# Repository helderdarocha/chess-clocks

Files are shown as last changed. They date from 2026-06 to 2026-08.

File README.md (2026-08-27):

# Chess Clocks (Arduino)

First model (Clock 1) using 3xAA batteries, TM1637 displays, and led-powered arcade buttons 
in a resin-coated wooden case.
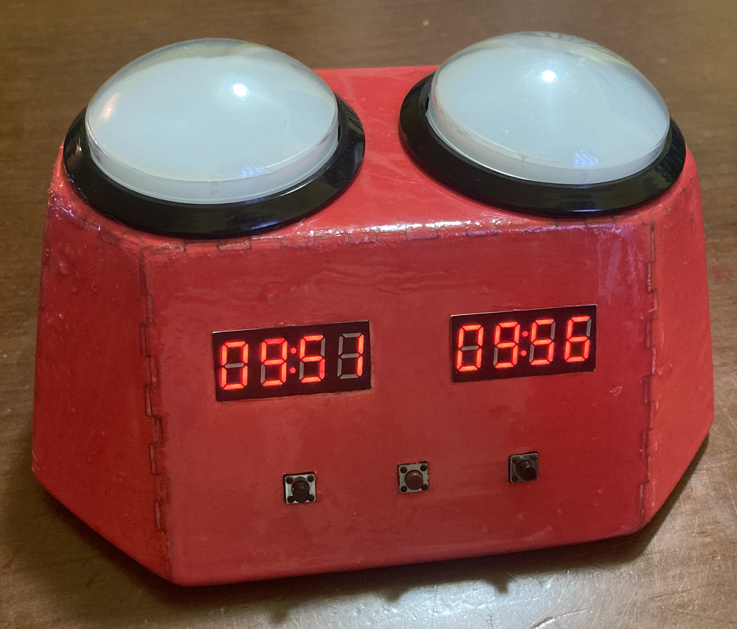
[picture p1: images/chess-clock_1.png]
Chess Clock 1


Old model (Clock 2) using 3xAA batteries, HT16K33 displays and pull-up resistors.
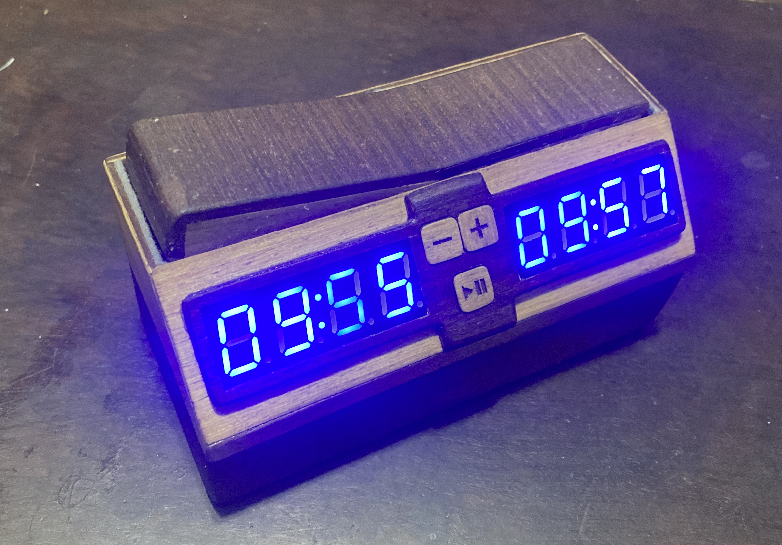
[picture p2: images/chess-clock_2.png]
Chess Clock 2


Current model (Clock 3) using Li-ion battery with TP4056 charger module.
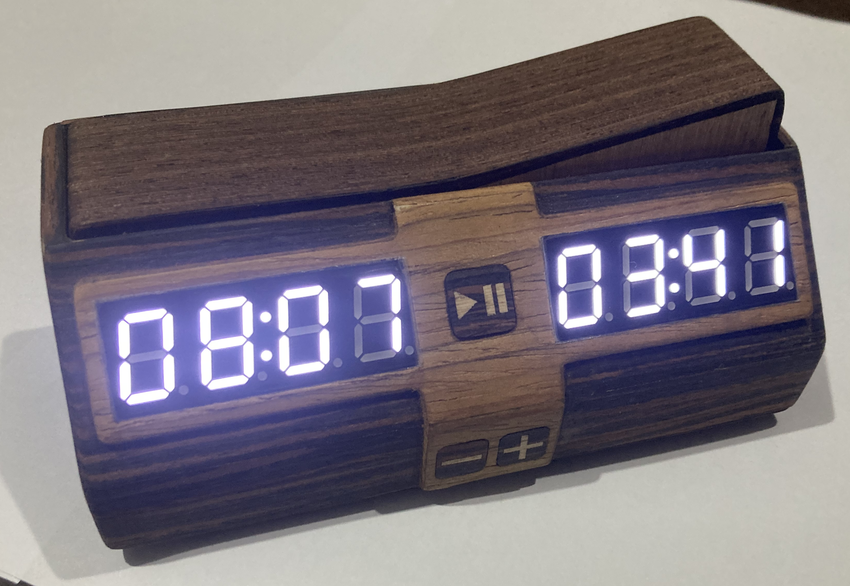
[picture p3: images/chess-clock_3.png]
Chess Clock 3


The current code in this repository, and list of material plus schematic/protoboard is for Clocks 2 and 3.

All have 20 presets for different time controls, including increment. Long pause allows adding or removing time during
a game. Sleep mode for power saving (after 5 minutes of inactivity). Optional DS3231 RTC module for
drift correction of the Arduino's millis() timer which uses a ceramic resonator instead of a crystal.

The cases were CNC-cut from 2mm basswood (the case for a second model-3 clock was also cut from transparent 2mm acrylic). The seesaw switch is mounted on the top of the case and uses magnets to attract
the switch to the left or right side. Two microswitches are mounted under the seesaw switch to detect which side is pressed.
Any slight movement of the seesaw switch will trigger a button press. The case was decorated with 0.5 mm wood sheets.

## Hardware

Materials used for this project:
- Arduino Pro Mini 3V3 8MHz (Clock 3) or Arduino Nano 5V 16MHz (Clock 2)
- 2x Adafruit-compatible HT16K33 4-digit 7-segment LED displays (I2C)
- Buzzer
- Buttons for each player (mounted as a pair of push buttons, or microswitches / seesaw switch)
- 3 control push buttons (start/pause/reset)
- 1 pull-up resistor for battery circuit (10k)
- Power supply (Clock 3: 3,7V Li-ion battery or Clock 2: 3x AA batteries)
- 3 100µF capacitors (to filter noise)
- 3 100nF capacitors (to filter noise)
- Schottky diode for reverse polarity protection
- BC548 transistor (Clock 3: for Li-ion battery circuit)
- 2N7000 MOSFET (Clock 3: for Li-ion battery circuit)
- TP4056 Li-ion battery charger module (Clock 3: for Li-ion battery circuit)
- DS3231 RTC module (optional, for accurate timekeeping)
- Enclosure and seesaw switch with magnets (CNC cut)
- On/off switch

Schematic for Clock 3 (I no longer use pull-ups resistors for the buttons - I rely on the internal pull-ups of the Arduino Pro Mini):
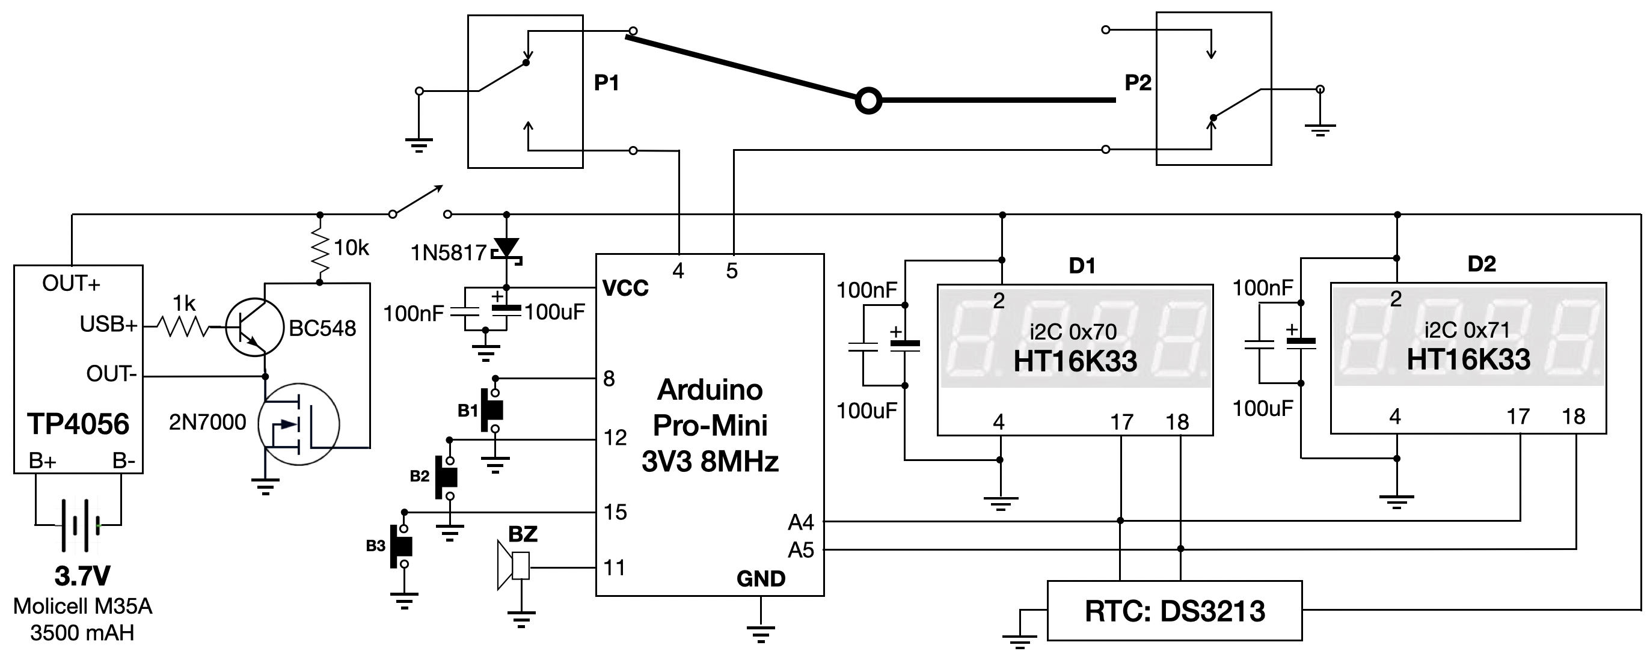
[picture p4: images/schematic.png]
Schematic


Protoboard layout for Clock 2 (A bit outdated and I still didn't draw an updated one for Clock 3):
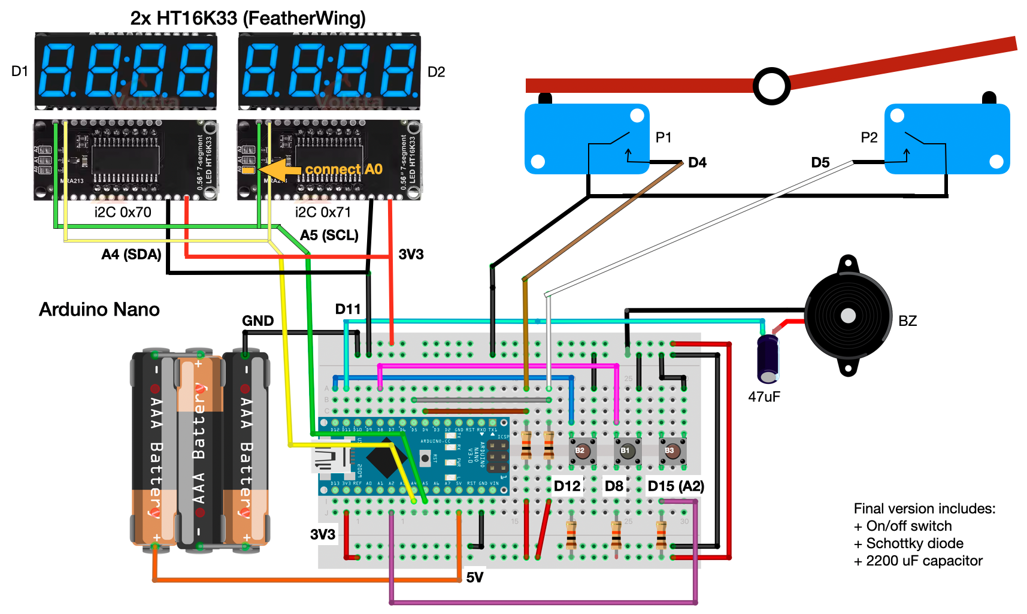
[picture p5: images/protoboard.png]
Protoboard


## Case design
The DXF files for CNC cutter (Clock 3):
- [2mm Basswood - 1.8mm slots](dxf/2mm-basswood.dxf)
- [2mm Acrylic - 2mm slots](dxf/2mm-acrylic.dxf)

CNC cutting layout screenshot for Clock 3 (this is what the file above looks like in Lightburn):
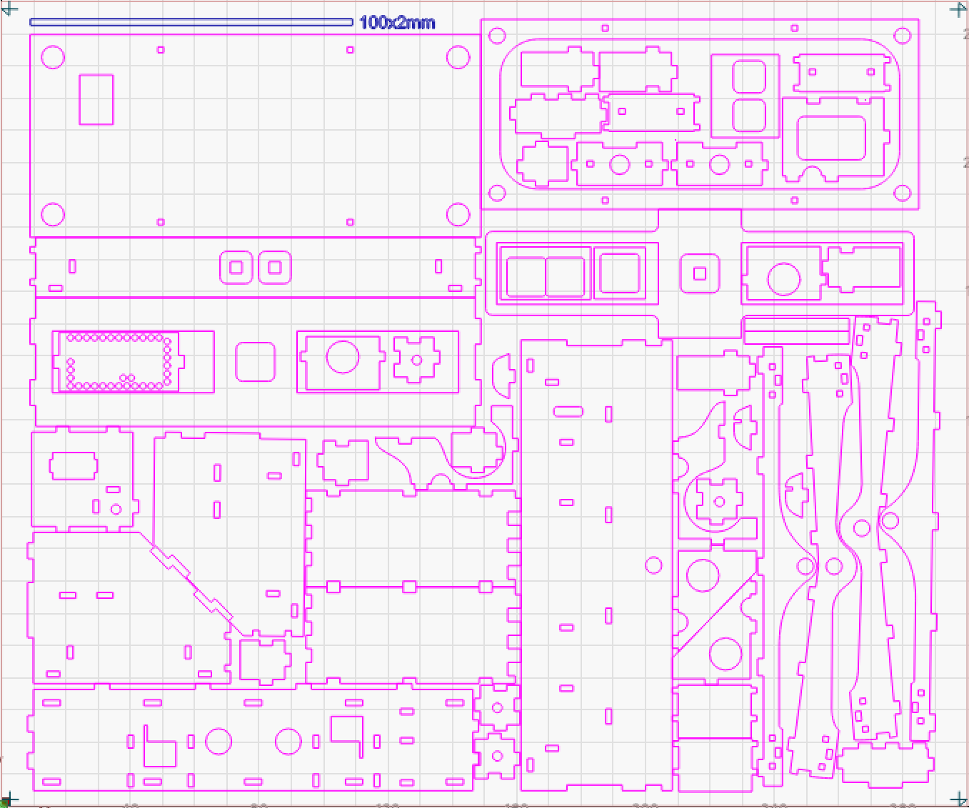
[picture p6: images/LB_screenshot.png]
CNC Layout - screenshot
  

Circuit in the case (Clock 2 - old model). Programming is possible via the USB port of the Arduino Nano. 
The case is closed by pressing the halves together. Repairing is harder than Clock 3 and there are too
many wires.
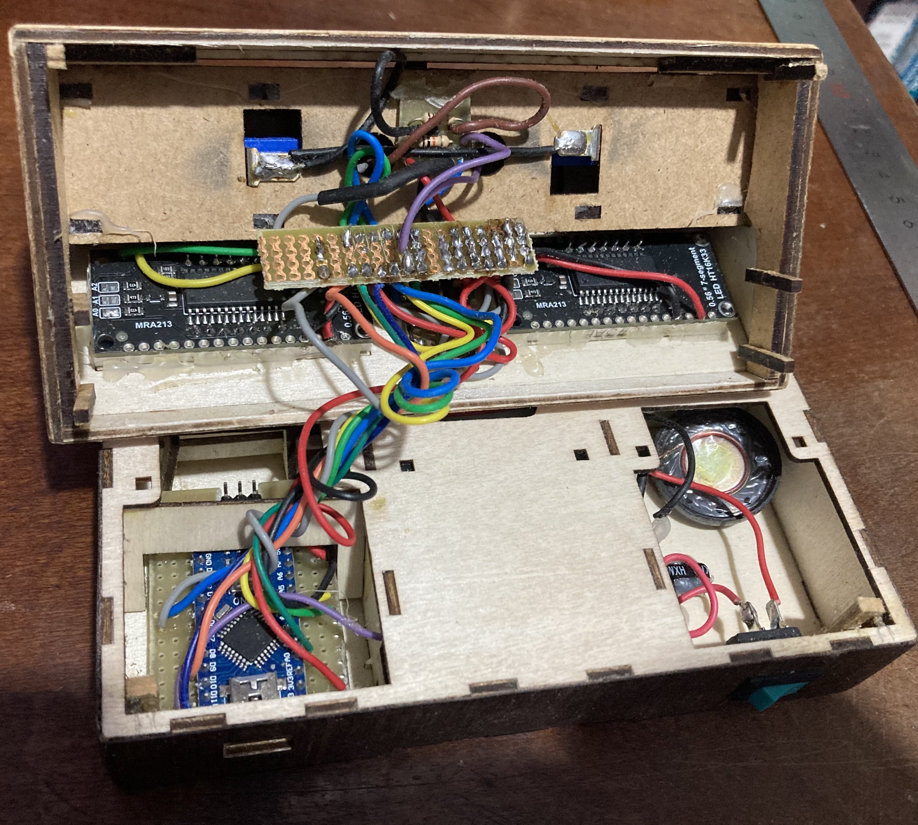
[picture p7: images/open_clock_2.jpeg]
Clock 2


Prototyping Clock 3. It uses a seesaw mechanism with 2 microswitches and magnets. The magnets are not used for
switching (I did not use a reed, as is common in many clocks), but to attract the seesaw switch to the left or right side. 
Any slight movement of the seesaw switch will trigger a button press.
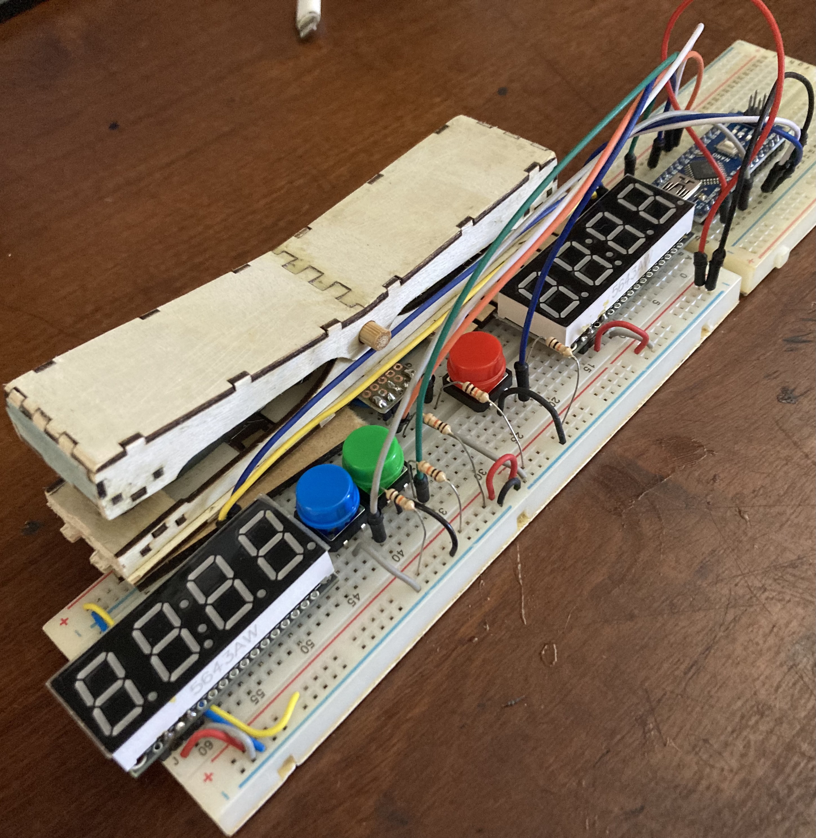
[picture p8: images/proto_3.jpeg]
Clock 3


Circuit in the (new) case during programming (Clock 3). Four rubber feet glued to screws are used to place
the lower cover. It still takes a long time to assemble, but it is easier to repair than the old model.
Programming requires an FTDI adapter, since it uses a Pro Mini. There are still too many wires (I need to design a PCB).
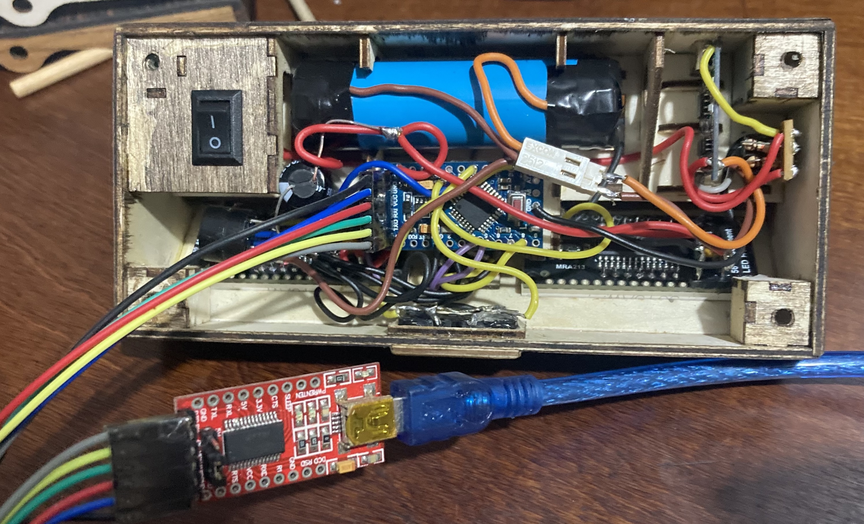
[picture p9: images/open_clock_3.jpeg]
Clock 2


Some ideas for the next projects include:
* A robust 3D printed case (will be cheaper, less fragile, lighter and faster to assemble)
* Use a PCB for most of the circuit (less wires, safer, more robust, lighter, cheaper, faster to build)
* Replace the Arduino with a RISC-V microcontroller or a Seeduino XIAO (cost, precision, efficiency)
* A clock with big displays and detachable arcade buttons modules for giant chess boards
* A clock with 4 displays and 4 detachable player modules

## Software

The code is written in C++ and uses the Arduino framework. Compile the `Chess_Clock_2` folder and upload to the correct Arduino board. 

## Project files

Files are in the `Chess_Clock_2` folder. They are used for both clocks, but the `config.h` file must be modified 
for the correct hardware configuration (battery, display, pins):

- `Chess_Clock_2.ino` - main sketch
- `config.h` - per-unit hardware configuration (battery, display, pins)
- `battery.h / battery.cpp` - battery voltage reading and low-battery warnings
- `notes.h, sound.h / sound.cpp` - buzzer tones and game-over melody
- `display.h / display.cpp` - 7-segment display rendering
- `power.h / power.cpp` - sleep mode for power saving
- `game.h / game.cpp` - game state machine and button handling, presets, seesaw switch macros
- `rtc.h / rtc.cpp` - optional DS3231: corrects millis() drift, no config needed

## User Guide
### Selecting the game duration
When powered on, the clock starts in game duration mode. To confirm the current duration, press ⏸️ / ▶️. This will put the clock into paused mode. Press ⏸️ / ▶️ again to start the countdown on the active display (the side of the raised lever).

To select a different duration, use ➕ to move forward or ➖ to go back. There are 20 preset game time options. The first display shows the option number and the second display shows the time in minutes + bonus in seconds:

- Bullet (00-03): 1+0, 1+1, 2+0, 2+1
- Blitz (04-07): 3+0, 3+2, 5+0, 5+3
- Rapid (08-13): 10+0, 10+5, 15+0, 15+10, 30+0, 30+15
- Classic (14-19): 45+0, 45+30, 60+0, 60+30, 90+0, 90+30

The clock remembers the last option selected, even after being turned off.

### To get started

Turn on the clock (power button). The displays show the last game duration used.

Position the lever so the starting player can press it when the game begins, and press ⏸️ / ▶️ to start the countdown with the current duration.

The clock enters game mode.

Each press of the lever adds a bonus in seconds (if the selected duration has a bonus set) before stopping the corresponding clock.

### Time adjustment
To adjust time during a game (to apply penalties):

1. Pause the game with ⏸️ / ▶️. The clock enters paused mode.
2. Press and hold ⏸️ / ▶️ for 2 seconds. The clock enters time adjustment mode. Only the first display will be lit.
3. If the first display's time is not to be changed, press ⏸️ / ▶️ to skip to the second display.
4. Adjust the time on the active display using the ➕ (adds 1 minute) and ➖ (removes 1 minute) buttons. To confirm, press ⏸️ / ▶️.
5. Pressing ⏸️ / ▶️ while the first display is lit selects the second display (turns off the first, turns on the second). Pressing this key again returns to paused mode.
6. To exit paused mode, press ⏸️ / ▶️ again to restart the countdown.

The clock displays time in MM:SS format up to 99:59. Larger values are shown in H:MM format (e.g., 1:40), with the ":" of the active clock blinking every half second. The clock returns to MM:SS format once the H:MM countdown drops below 1:38. The maximum supported time is 9:59:59.

### End of game
When a player's time reaches zero, game mode ends:

1. The clocks stop counting (finished mode)
2. A tune is played

To start a new game after time has run out, press ⏸️ / ▶️.

### Restart
To restart at any time, turn the clock off and back on (power button) or, while paused or finished, press the ➕ and ➖ buttons simultaneously. The clock restarts (in game duration mode) with the last duration used.

### Operation and power
On startup, if the batteries need to be replaced, the displays will flash the message BAtt Lo-- twice along with three soft beeps, before displaying the game duration. The sounds will repeat every minute while the clock is on.

The clock will enter low-power mode and turn off the displays if it is not in game mode (counting time) and remains untouched — with no button or lever pressed — for more than 5 minutes. Pressing any button or lever will wake the clock.

In low-power mode, consumption is very low but not zero. After using the clock, turn it off.

To charge the battery, connect a USB-A to USB-C cable to the back of the clock. When charging is complete, the indicator LED will turn blue. USB-C to USB-C cables do not work on older clocks.

### Other features
These features were added recently and not yet documented:
- Turn sound off pressing the ➖ button for 3 seconds, or turn sounds on pressing ➕ for 3 seconds, when paused.
  Turning off sound does not turn off the Low Battery beep at startup.
- View how many moves were played and total time by pressing ➖ when paused. 
- A user-defined timeset/bonus preset can be added by long pausing in the initial preset screen. It will be added
at position 20. You can adjust 0-9 hours, 0-59 minutes, and 0-59 bonus seconds by adding / subtracting to individual digits.
A new user-defined preset overrides it.

### Experimental features (not yet committed in the main branch)
- Adjust LED brightness
- Inform % of battery remaining

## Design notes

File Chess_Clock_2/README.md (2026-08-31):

# Chess Clock 2 - codebase

This project is a chess clock implemented using an Arduino board. The code is written in C++ and uses the Arduino 
framework. The main functionality of the clock is to manage the timing of chess games. Time controls
are saved as presets, which the user can select before starting a game. The clock supports the most popular time 
controls, including Bullet, Blitz, Rapid, and Classic formats, including bonus time, and the user can also save a 
custom time control and bonus. It is a reliable and easy-to-use chess clock that can be used in tournaments.

Time switches between players are handled by a lever, which the players press to indicate that they have completed 
their turn. The Arduino reads the lever's state and switches the active clock, adding bonus time if applicable. 
During the game, the user can pause the clock, adjust the time for penalties (adding or subtracting minutes, and
resume the countdown. 

Other features include a low-battery warning (which appears as a message at startup and a beep), sleep mode for power 
saving, stats display (total time and number of moves), options to turn the sound on or off, and an optional game-over 
melody when a player's time runs out. The code also supports a DS3231 real-time clock module to correct the drift in
boards that don't have a precise crystal oscillator (most Arduino boards).

The clock can display time in MM:SS format up to 99:59. Larger values are shown in H:MM format. The maximum supported 
time is 9:59:59.

This code is used by three models of chess clocks, which differ in the power supply and display type. The model must be
selected in the `config.h` file before compiling the code. 

The code is designed to be modular, with separate files for battery management, display rendering, sounds, 
power management, game state, and real-time clock (RTC) support.

Below is a brief description of the main files in the codebase:

- **Chess_Clock_2.ino**: This is the main sketch file. It includes the other files and contains the standard Arduino 
   `setup()` and `loop()` functions.
- **config.h**: This file contains the per-unit hardware configuration. It defines the battery type, display type,
    and pin assignments for the buttons and lever. The user must modify this file to match the hardware configuration
    of their specific chess clock model before compiling the code.
- **game.h** / **game.cpp**: This is the main code of the chess clock. It handles the game state machine and button
    handling. The code manages the different states of the clock (selecting game duration, paused, running, finished,
    time adjustment, etc.), button presses and lever movement. The code also defines the presets for the different time
    controls and bonus time. Its main function (`clockUpdate()`) is called from the main loop and updates the clock state
    based on the current state and user input.
- **display.h** / **display.cpp**: These files handle the rendering of the 7-segment displays. The functions in these
    files are responsible for displaying the time, game duration, and status messages on the displays (except for
    the "bAtt Lo--" message, which is handled by the battery code), and turning on and off the displays as needed.
- **battery.h** / **battery.cpp**: These files handle battery voltage reading and low-battery warnings. The code reads the
    battery voltage and displays a warning message if the voltage drops below a certain threshold. The threshold depends
    on the battery type and is defined in the `config.h` file. The threshold for AA batteries was set based on Alkaline
    batteries, and may need to be adjusted for NiMH batteries, for example. The code also includes a low-battery warning
    beep and shows "bAtt Lo--" at startup on the display when the battery is low.
- **power.h** / **power.cpp**: These files handle the sleep mode for power saving. The function puts the Arduino into
    sleep mode after a certain period of inactivity (no button presses or lever movement and not running a game). The
    clock leaves sleep mode when a button is pressed or the lever is moved.
- **rtc.h** / **rtc.cpp**: These files handle the optional DS3231 real-time clock module. The code reads the time from
    the DS3231 and uses it to correct the drift in the Arduino's `millis()` function. If a DS3231 is not present, the code
    will still work, but the time may drift if the board used does not have a precise crystal oscillator.
- **sound.h** / **sound.cpp**: These files handle the buzzer tones. The code generates different
    tones for button presses, low-battery warnings, and a melody (or three long beeps) when a player's time runs out.
    The sound can be turned on or off by the user using the minus and plus buttons. Some sound options are set in the
    `config.h` file (use beeps or a game-over melody).

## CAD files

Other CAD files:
dxf/2mm-basswood.dxf
dxf/2mm-acrylic.dxf

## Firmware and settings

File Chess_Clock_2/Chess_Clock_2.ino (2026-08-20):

/* Chess Clock 2 - For Clock models CMX-2 and CMX-3
 * Version 2.1.0 (added move count and total time stats - 2026-08-19)
 * @author Helder da Rocha
 */

#include <Arduino.h>

#include "config.h"     // per-unit hardware configuration (battery, display, pins)
#include "battery.h"    // battery voltage reading and low-battery warnings
#include "sound.h"      // buzzer tones and game-over melody
#include "display.h"    // 7-segment display rendering
#include "power.h"      // sleep mode for power saving
#include "game.h"       // game state machine and button handling, presets, seesaw switch macros
#include "rtc.h"        // optional DS3231: corrects millis() drift, no config needed

#include <Wire.h>                 // i2C support
#include <Adafruit_GFX.h>         // Displays
#include "Adafruit_LEDBackpack.h" // Displays

/* ================= Hardware ================= */
// Pins, display addresses, and brightness levels now live in config.h

// Displays
Adafruit_7segment d1;
Adafruit_7segment d2;

/* ================= Power saving and battery warning variables ================= */
// Battery/idle thresholds now live in config.h

unsigned long lastActivityMs = 0;   // updated on every button press
unsigned long lastRunningMs = 0;    // updated when the clock is RUNNING (for idle timeout)
bool sleeping = false;
bool justWokeUp = false;
bool awaitingButtonRelease = false;

/* ================= Control buttons ================= */
// Pause + select + increment/decrement
bool prevPause = HIGH,
prevPlus = HIGH,
prevMinus = HIGH;

// Game latch
bool prevP1 = HIGH,
prevP2 = HIGH;

// To control increments and pausing using PAUSE button
unsigned long pausePressTime = 0;
bool pauseLongFired = false;

// To reset using + and - buttons
unsigned long resetPressTime = 0;
bool resetLongFired = false;

// To toggle sound on/off using + and - buttons (held 3s while PAUSED)
unsigned long plusPressTime = 0;
bool plusLongFired = false;
unsigned long minusPressTime = 0;
bool minusLongFired = false;

//////////////////// FUNCTIONS ////////////////////////////

// Battery reading/warning functions live in battery.h/battery.cpp
// Sleep functions live in power.h/power.cpp
// Sound functions and the melody data live in sound.h/sound.cpp
// Display rendering functions live in display.h/display.cpp
// Presets, game/turn state, and the state-machine handlers live in game.h/game.cpp

//////////// ARDUINO CONTROL - setup() and loop() //////////////////

/* ================= SETUP ================= */

void setup() {
    // Player lever
    pinMode(PLY1, INPUT_PULLUP);
    pinMode(PLY2, INPUT_PULLUP);

    // Pause LED
    pinMode(LED_PAUSE, OUTPUT);
    digitalWrite(LED_PAUSE, LOW);

    // Control buttons
    pinMode(PAUSE_BTN, INPUT_PULLUP);
    pinMode(PLUS_BTN, INPUT_PULLUP);
    pinMode(MINUS_BTN, INPUT_PULLUP);

    // Buzzer
    pinMode(BUZZER, OUTPUT);

    // Displays
    Wire.begin();
    d1.begin(DISPLAY_ADDRESS_1);
    d2.begin(DISPLAY_ADDRESS_2);
    d1.setBrightness(DISPLAY_ON);
    d2.setBrightness(DISPLAY_ON);

    // Warn if battery is low - beep even if sound is off!
    checkBatteryAtStartup(d1, d2);

    // Load saved sound on/off preference after alerting about battery, so the user can hear the warning even if sound was off last time.
    soundInit();

    // Detect an optional DS3231; falls back to plain millis() if absent
    rtcInit();

    // Load persisted preset, apply it, draw preset-selection screen
    clockInit(d1, d2);

    noTone(BUZZER);
}

/* ================= LOOP ================= */
void loop() {
    // Read button states
    bool pauseNow = digitalRead(PAUSE_BTN);
    bool plusNow = digitalRead(PLUS_BTN);
    bool minusNow = digitalRead(MINUS_BTN);
    bool p1Now = digitalRead(PLY1);
    bool p2Now = digitalRead(PLY2);

    bool pausePressed = PRESSED(pauseNow, prevPause);
    bool pauseReleased = (pauseNow == HIGH && prevPause == LOW);

    // Pause was pressed
    if (pausePressed) {
        pausePressTime = millis();
        pauseLongFired = false;
    }

    // Long pause was pressed - to increment or decrement user time
    bool pauseLong = false;
    if (pauseNow == LOW && !pauseLongFired && millis() - pausePressTime >= 2000) {
        pauseLong = true;
        pauseLongFired = true;
    }

    // + and - buttons were pressed to reset the clock
    bool resetCombo = (plusNow == LOW && minusNow == LOW);
    if (resetCombo && !resetLongFired && resetPressTime == 0) {
        resetPressTime = millis();
    }
    if (!resetCombo) {
        resetPressTime = 0;
        resetLongFired = false;
    }
    bool resetLong = false;
    if (resetCombo && !resetLongFired && resetPressTime > 0 && millis() - resetPressTime >= 1000) {
        resetLong = true;
        resetLongFired = true;
    }

    // + or - held alone (not the reset combo) for 3s while PAUSED toggles sound on/off.
    // Tracked unconditionally here, like the other button timers; game.cpp only acts
    // on these while in the PAUSED state.
    if (PRESSED(plusNow, prevPlus)) {
        plusPressTime = millis();
        plusLongFired = false;
    }
        bool plusLong = false;
        if (plusNow == LOW && !plusLongFired && millis() - plusPressTime >= 3000) {
        plusLong = true;
        plusLongFired = true;
    }

        if (PRESSED(minusNow, prevMinus)) {
        minusPressTime = millis();
        minusLongFired = false;
    }
        bool minusLong = false;
        if (minusNow == LOW && !minusLongFired && millis() - minusPressTime >= 3000) {
        minusLong = true;
        minusLongFired = true;
    }

    // Release edge for "-", used while PAUSED to open the move-info screen
    // (short tap) without conflicting with the 3s hold-to-mute above (see
    // minusLongFired passed alongside it into clockUpdate()).
    bool minusReleased = (minusNow == HIGH && prevMinus == LOW);


    // A button was pressed to wake up the clock after sleep mode (pause, plus/minus or player levers)
    if (pausePressed || PRESSED(plusNow, prevPlus)
                     || PRESSED(minusNow, prevMinus)
                     || PRESSED(p1Now, prevP1)
                     || PRESSED(p2Now, prevP2)) {
        lastActivityMs = millis();
    }

    rtcUpdate();  // throttled internally; no-op if no RTC was found

    if (resetLong && !isRunning()) {
        resetToSelectDuration(d1, d2);
    }

    if (isRunning()) {
        lastRunningMs = millis();  // used to calculate idle timeout
    }

    // will sleep if idle for too long and not running (wakes up on any button press)
    // if the clock was running, and just changed state automatically (game over), it will wait IDLE_TIMEOUT_MS
    // before sleeping, to give the user a chance to see the result and hear the game over tune.
    if (!sleeping && !isRunning()
                  && millis() - lastActivityMs > IDLE_TIMEOUT_MS
                  && millis() - lastRunningMs > IDLE_TIMEOUT_MS) {
        goToSleep(d1, d2, sleeping, justWokeUp, lastActivityMs,
                  isSelectingDuration(), getPresetIndex(), getPresetTimeMs(),
                  getPlayer1Time(), getPlayer2Time());
    }

    if (justWokeUp) {
        justWokeUp = false;
        rtcNotifyWake();    // necessary because RTC is powered independently.
        awaitingButtonRelease = true;  // swallow whichever button(s) caused the wake
    } else if (awaitingButtonRelease) { // Woke up, but button may not have been released yet
        // Ignore all button (not lever) activity until everything is released, so the
        // press that woke the clock — and its eventual release — can't
        // also be interpreted as a deliberate press by the state machine.
        if (pauseNow == HIGH && plusNow == HIGH && minusNow == HIGH) {
            awaitingButtonRelease = false;
        }
    } else { 
        clockUpdate(plusNow, prevPlus, minusNow, prevMinus,
                    pausePressed, pauseReleased,
                    pauseLong, pauseLongFired,
                    plusLong, minusLong,
                    minusReleased, minusLongFired,
                    p1Now, prevP1, p2Now, prevP2,
                    d1, d2);
    }

    // PAUSE LED: on while PAUSED or showing the move-info screen (which is
    // just a brief detour off PAUSED, not a real gameplay state), off in
    // every other state and while sleeping (goToSleep() also turns it off
    // before it blocks, since this line won't run again until after the
    // clock wakes).
    digitalWrite(LED_PAUSE, ((isPaused() || isShowingMoveInfo()) && !sleeping) ? HIGH : LOW);

    if (pauseNow == HIGH) {
        pauseLongFired = false;
    }
    if (plusNow == HIGH) {
        plusLongFired = false;
    }
    if (minusNow == HIGH) {
        minusLongFired = false;
    }

    prevPause = pauseNow;
    prevPlus = plusNow;
    prevMinus = minusNow;
    prevP1 = p1Now;
    prevP2 = p2Now;

    delay(40);

    noTone(BUZZER);
}

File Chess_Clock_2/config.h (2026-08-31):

/* ================================================================
 * config.h — Hardware configuration
 * Created by Helder da Rocha on 11/07/26.
 *
 * These values may change between physical clock builds (battery type, LED color, wiring).
 * Set MODEL below to match the physical unit — everything else in this file
 * is derived from it automatically.
 *
 * Currently we have:
 * - Chess clock CMX-1 - Not supported
 * - Chess clock CMX-2 - 2 AA batteries and blue display + Arduino Nano
 * - Chess clock CMX-3W - 1 LiPo battery and white display + Arduino Pro Mini
 * - Chess clock CMX-3Y - 1 LiPo battery and yellow display + Arduino Pro Mini
 * ================================================================ */

//#ifndef CHESS_CLOCKS_ARDUINO_CONFIG_H
//#define CHESS_CLOCKS_ARDUINO_CONFIG_H
//#endif //CHESS_CLOCKS_ARDUINO_CONFIG_H
#pragma once

#include <Arduino.h>

/* ----- CHOOSE THE CLOCK MODEL! -----
 * This is the only line you should need to change. Power source (and its
 * low-battery threshold) and display LED color/brightness are all derived
 * automatically from the model below — see the "Derived from MODEL" blocks
 * further down. Don't set POWER_SOURCE or DISPLAY_LED_COLOR directly.
 */
#define CMX_1   1   // Not supported
#define CMX_2   2   // 3x AA batteries, blue display, Arduino Nano
#define CMX_3W  3   // LiPo battery, white display, Arduino Pro Mini
#define CMX_3Y  4   // LiPo battery, yellow display, Arduino Pro Mini

// **** UNCOMMENT THE REQUIRED LINE ****
//#define MODEL CMX_1
//#define MODEL CMX_2
//#define MODEL CMX_3W
#define MODEL CMX_3Y

/* ---------------- Power source ---------------- */
#define BATT_3XAA  1   // 3x AA (Alkaline ~4.5V or NiMH ~3.6V full charge)
#define BATT_LIPO  2   // Single internal LiOn/LiPo cell, 3.7V nominal

// Derived from MODEL above — do not edit these two lines directly.
#if MODEL == CMX_2
  #define POWER_SOURCE  BATT_3XAA
#elif MODEL == CMX_3W || MODEL == CMX_3Y
  #define POWER_SOURCE  BATT_LIPO
#else
  #error "Unsupported or unset MODEL in config.h (CMX_1 is not supported; pick CMX_2, CMX_3W, or CMX_3Y)"
#endif

// Low battery threshold, considering ~1.1V AREF and protection circuit drop
#if POWER_SOURCE == BATT_3XAA
  #define BATT_WARN_MV  2950UL   // 3 AA batteries + Schottky diode (~3.0V on VCC pin at minimum)
#elif POWER_SOURCE == BATT_LIPO
  #define BATT_WARN_MV  3050UL   // Internal Molicell M35A 3.7V LiOn (~2.7V on VCC pin at minimum)
#else
  #error "POWER_SOURCE not set in config.h"
#endif

// Periodic battery check interval (ms). Checked at startup and then at most once every BATT_CHECK_MS.
#define BATT_CHECK_MS  60000UL   // 60 seconds

/* ---------------- Display ---------------- */
// Select the LED color used by THIS unit's displays.
#define DISPLAY_LED_WHITE  1
#define DISPLAY_LED_BLUE   2
#define DISPLAY_LED_YELLOW 3
#define DISPLAY_LED_FULL   0

// **** DEPENDS on MODEL — derived below, do not edit directly ****
#if MODEL == CMX_2
  #define DISPLAY_LED_COLOR  DISPLAY_LED_BLUE
#elif MODEL == CMX_3W
  #define DISPLAY_LED_COLOR  DISPLAY_LED_WHITE
#elif MODEL == CMX_3Y
  #define DISPLAY_LED_COLOR  DISPLAY_LED_YELLOW
#else
  #error "Unsupported or unset MODEL in config.h (CMX_1 is not supported; pick CMX_2, CMX_3W, or CMX_3Y)"
#endif

// Brightness actually applied at runtime via setBrightness(); differs by LED color.
#if DISPLAY_LED_COLOR == DISPLAY_LED_WHITE
  #define DISPLAY_ON 15
#elif DISPLAY_LED_COLOR == DISPLAY_LED_BLUE
  #define DISPLAY_ON 15
#elif DISPLAY_LED_COLOR == DISPLAY_LED_YELLOW
  #define DISPLAY_ON 15  
#elif DISPLAY_LED_COLOR == DISPLAY_LED_FULL
  #define DISPLAY_ON 15
#else
  #error "DISPLAY_LED_COLOR not set in config.h"
#endif

// Used to turn off the displays
#define DISPLAY_OFF 0

// I2C addresses of the two 7-segment displays. Do not change (unless you know what you're doing).
#define DISPLAY_ADDRESS_1 0x70
#define DISPLAY_ADDRESS_2 0x71

/* ---------------- Sound ---------------- */
// Select what plays when a player's time runs out (see gameOverTune() in sound.cpp).
#define GAME_OVER_TUNE   1   // the full melody (default, unchanged)
#define GAME_OVER_BEEPS  2   // three long beeps, for those who find the melody annoying

// **** UNCOMMENT THE REQUIRED LINE ****
#define GAME_OVER_SOUND      GAME_OVER_TUNE    // <-- CHANGE
//#define GAME_OVER_SOUND      GAME_OVER_BEEPS   // <-- CHANGE

// Sounds can be turned off completely (for tournaments), pressing the "-" button for 3 seconds while PAUSED.
// The buzzer may still be used for low-battery warnings even if sound is off.

/* ---------------- Arduino Pins ---------------- */
// Reserved for pause LED if present
#define LED_PAUSE 3

// Player levers
#define PLY1      4
#define PLY2      5

// Reserved for player LEDs if present
#define LED_PLY1 6
#define LED_PLY2 7

// Control buttons
#define PAUSE_BTN 8
#define PLUS_BTN  12
#define MINUS_BTN 15

#define BUZZER    11
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

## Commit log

2026-06-02 Updated version 1.5. - Added hardware-based surge protection (a 2200uF capacitor) - Added low battery warning - Added reset by pressing + and - at the same time for 2 seconds - Added low-power mode i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
2026-06-02 Updated README.md.
    [Basswood_2mm_parts.dxf, MDF_2.5mm_parts.dxf]
2026-07-12 Uploaded version 2 (refactored and improved)
    [2mm-acrylic.dxf, 2mm-basswood.dxf, Basswood_2mm_parts.dxf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]
2026-08-27 New features: - Slot for programmable timeset (time + bonus) - Model selection in config.h
